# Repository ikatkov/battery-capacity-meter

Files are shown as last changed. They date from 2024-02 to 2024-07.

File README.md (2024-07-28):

# Assembly notes

Vref pin on Arduino Pro Mini breakout board is not on any pin, solder a wire to capacitor between 
pins 12 and 13. To the pin13 end.

Manufactured PCBs have a defect, bridge these tracks
see manufactured-pcb-defect.png

# 7 Segments text

Here is an example of which letters are possible

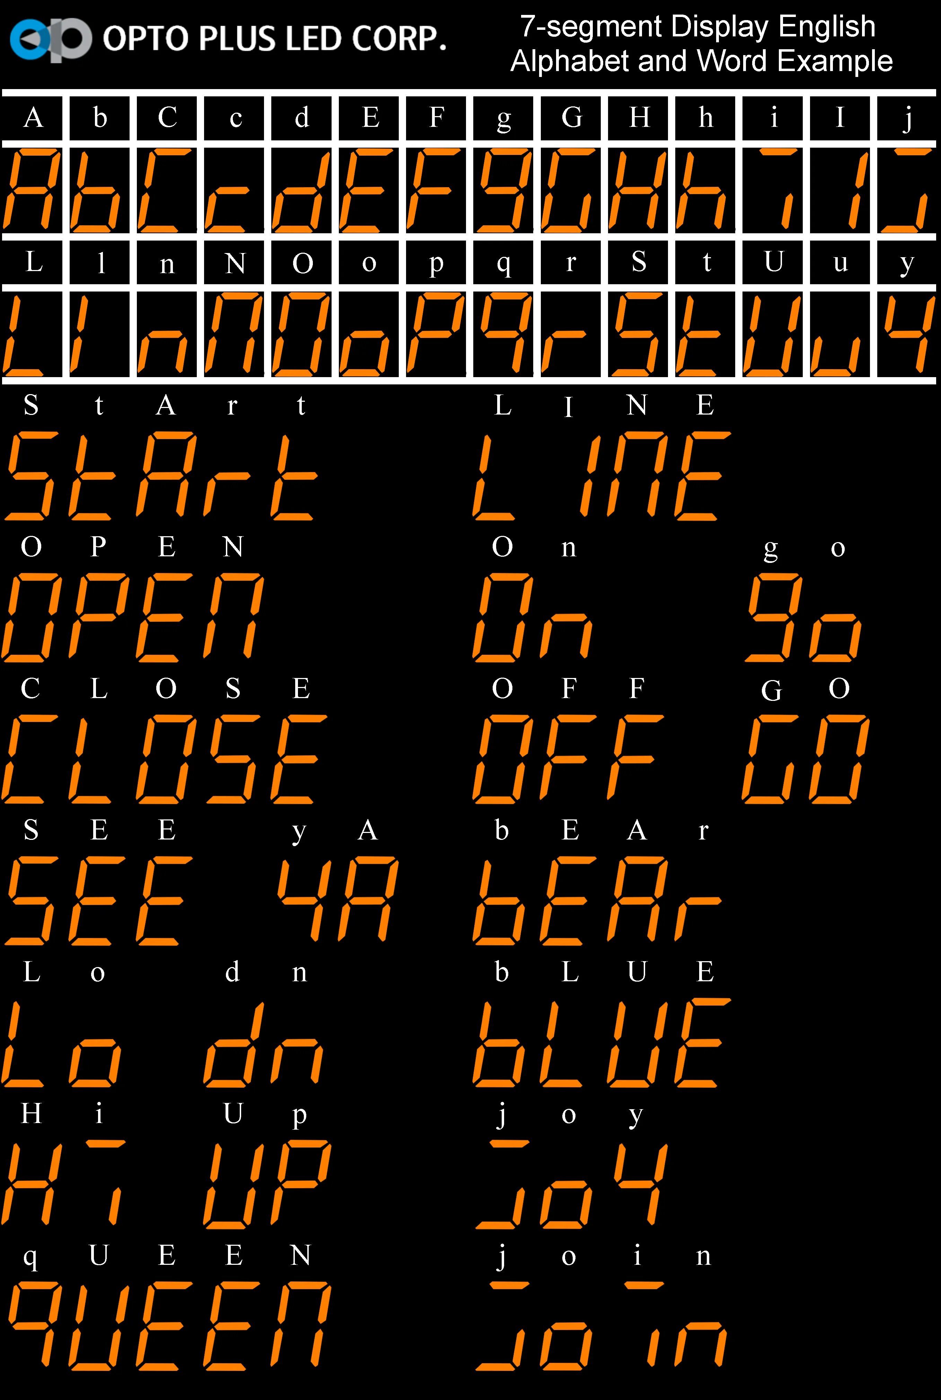
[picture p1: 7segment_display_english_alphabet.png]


A,b,C,c,d,E,F,g,G,H,h,i,I,j,L,l,n,N,O,o,P,q,r,S,t,U,u,y

# Notes

* The final PCB layout that I ordered from https://jlcpcb.com/ is not great. This is my almost first attempt to really use two sides with a lot of vias. Maybe next time use the lower side for horizontal signal traces and the top side for vertical? 

* Maybe replace 2.5V ref to MCU with feeding the whole MCU from 2.5V ref, it eliminates the extra wire.

* Next time make use wider ribbon cable - use more LEDs on the front panel to indicate the current mode and state

* Update the firmware to include trickle charge, it's especially noticeable when charging to the 3.8V for storage, once 
charging power is removed - voltage drops.

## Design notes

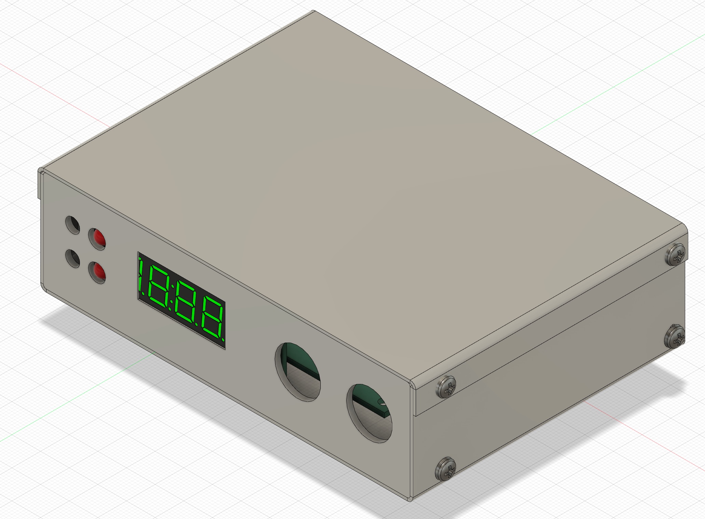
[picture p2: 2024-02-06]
box.jpg

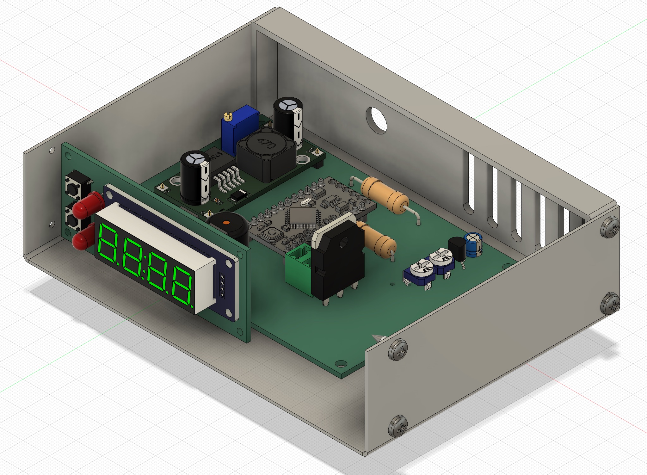
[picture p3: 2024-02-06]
box-inside.jpg

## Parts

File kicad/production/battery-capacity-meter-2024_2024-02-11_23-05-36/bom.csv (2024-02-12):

Designator | Footprint | Quantity | Value | LCSC Part #
AREF1 | SolderWire-0.5sqmm_1x01_D0.9mm_OD2.1mm | 1 | Pin20
BZ1 | Buzzer_12x9.5RM7.6 | 1 | Buzzer
Battery1 | JST_VH_B2P-VH-B_1x02_P3.96mm_Vertical | 1 | Charger
C1 | 1206 | 1 | 10n
C2 | 1206 | 1 | 100n
C4, C6 | 1206 | 2 | 10u
C5 | 1206 | 1 | 1u
C8 | 1206 | 1 | 100p
C9 | CP_Radial_D5.0mm_P2.50mm | 1 | 10u
D1 | D_DO-41_SOD81_P10.16mm_Horizontal | 1 | 1N4004
D2, D6 | D_MiniMELF | 2 | 1N4148
D3 | LED_D5.0mm | 1 | CHARGE
D4 | LED_D5.0mm | 1 | 1A
D5 | D_MiniMELF | 1 | 1N4732A 4.7V
D7, D9 | SOT-23 | 2 | BAT54S
H1, H2, H3, H4 | MountingHole_3.2mm_M3 | 4 | MountingHole
H5, H6, H7, H8 | MountingHole_2.2mm_M2 | 4 | MountingHole
J3 | IDC-Header_2x04_P2.54mm_Vertical | 1 | Conn_MainBoard
J4 | IDC-Header_2x04_P2.54mm_Vertical_SMD | 1 | Conn_DisplayBoard
J5 | JST_XH_B2B-XH-A_1x02_P2.50mm_Vertical | 1 | PWR
Q1 | SOT-23 | 1 | 2N3904
Q2 | SOT-23 | 1 | 2N3906
Q3 | TO-3P-3_Vertical | 1 | 2SD2390
Q6 | TO-220-3_Vertical | 1 | X0402MF
R1 | R_Axial_DIN0614_L14.3mm_D5.7mm_P15.24mm_Horizontal | 1 | 0.2-0.5R
R10, R11, R2, R20, R21, R22, R24, R25, R6, R7, R8 | 0805 | 11 | 10k
R12 | R_Axial_DIN0614_L14.3mm_D5.7mm_P25.40mm_Horizontal | 1 | 1R
R13, R16 | 0805 | 2 | 470
R14 | 0805 | 1 | 2k
R15, R18, R5, R9 | 0805 | 4 | 1k
R17 | 0805 | 1 | 680
R19 | 0805 | 1 | 3k
R23 | 2512 | 1 | R100
R26 | 0805 | 1 | 150R
R27 | 0805 | 1 | 1M
R3, R4 | 0805 | 2 | 2.2k
RV1, RV2 | Potentiometer_Runtron_RM-065_Vertical | 2 | 500
SW1 | SW_PUSH_6mm | 1 | CHARGE/DISCHARGE
SW2 | SW_PUSH_6mm | 1 | 1A MODE
TH1, TH2 | PTC_1A_radial | 2 | 1A
TP1 | SolderWire-0.5sqmm_1x01_D0.9mm_OD2.1mm | 1 | ISet
U1 | LM2596_StepDown_pot | 1 | LM2596_StepDown_Module
U10, U5, U9 | SOT-23 | 3 | AO3406
U2 | SO-8_3.9x4.9mm_P1.27mm | 1 | LM358
U3 | 7segments-medium | 1 | TM1637Display
U6 | TO-92_Wide | 1 | TL431LP
U7 | ARDUINO_PRO_MINI_NO_PRG_HEADER | 1 | Arduino_pro_mini
U8 | SO-8_3.9x4.9mm_P1.27mm | 1 | TP4056

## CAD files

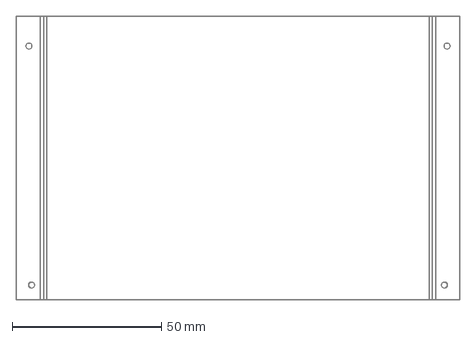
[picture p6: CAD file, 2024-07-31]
3d/top.dxf
148.5 x 95.0 mm

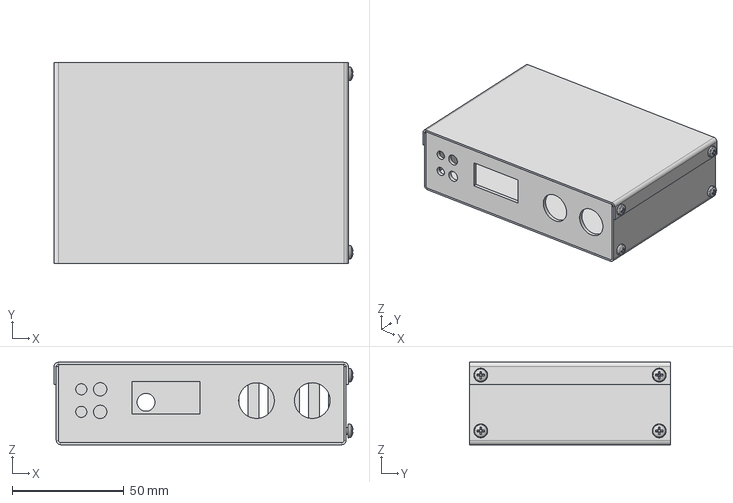
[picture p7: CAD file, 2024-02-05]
3d/enclosure.step
134.0 x 90.0 x 37.0 mm
Type II Cross Recessed Pan Head Tapping Screw ANSI B18.6.4 5-20 x 0.3 75 Type AB Steel Grade 2 Plain v1 x 4

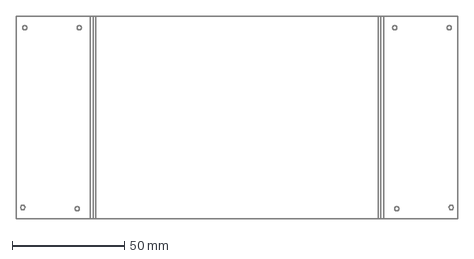
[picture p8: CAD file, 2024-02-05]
3d/bottom.dxf
196.5 x 90.0 mm

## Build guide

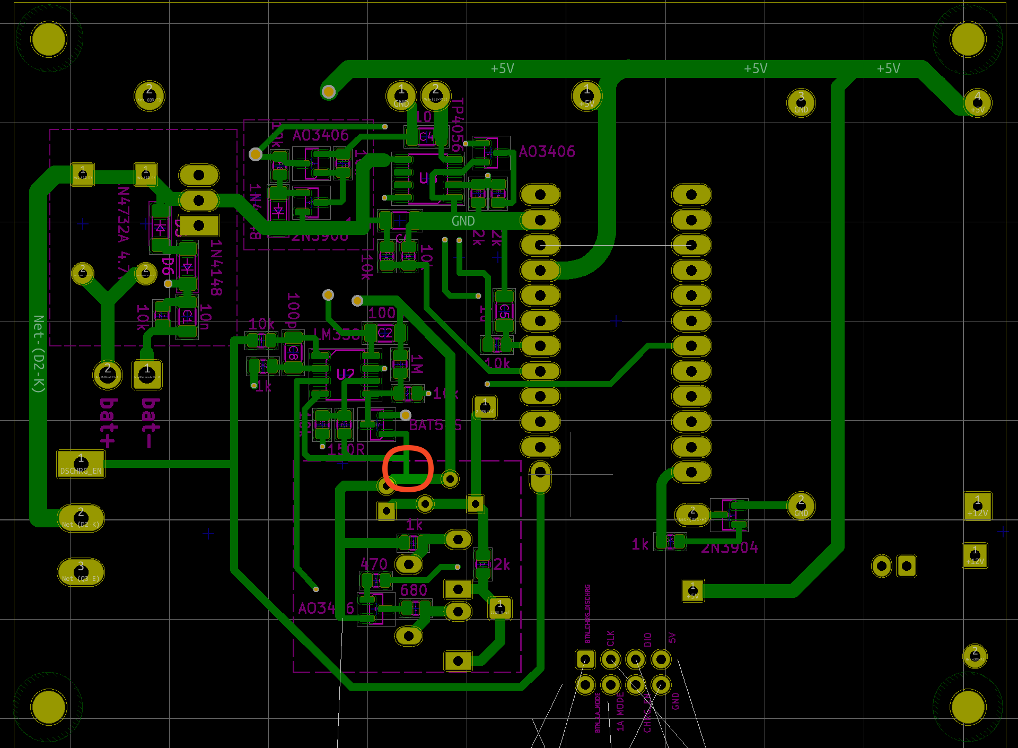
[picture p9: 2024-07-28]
manufactured-pcb-defect.png

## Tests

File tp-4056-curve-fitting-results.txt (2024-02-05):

0.5A 
=====
Fitted parameters for 4th-degree polynomial:  0.27035568*pow(voltage, 4) + -0.51039031*pow(voltage, 3) + 0.31013550*pow(voltage, 2) + 0.44244364*voltage + 0.00128515
Fitted parameters for 3rd-degree polynomial:  0.09325863*pow(voltage, 3) + -0.13783420*pow(voltage, 2) + 0.56727601*voltage + -0.00927211
Fitted parameters for 2nd-degree polynomial:  0.02794441*pow(voltage, 2) + 0.48445722*voltage + 0.00029737
Fitted parameters for linear function:  0.51579271*voltage + -0.00502295

1A 
=====
Fitted parameters for 4th-degree polynomial:  -0.50940504*pow(voltage, 4) + 1.11893064*pow(voltage, 3) + -0.80032945*pow(voltage, 2) + 1.19824953*voltage + -0.01151128
Fitted parameters for 3rd-degree polynomial:  0.02641582*pow(voltage, 3) + -0.03749443*pow(voltage, 2) + 1.00662362*voltage + 0.00093661
Fitted parameters for 2nd-degree polynomial:  0.00539237*pow(voltage, 2) + 0.98790520*voltage + 0.00265263
Fitted parameters for linear function:  0.99337865*voltage + 0.00176501

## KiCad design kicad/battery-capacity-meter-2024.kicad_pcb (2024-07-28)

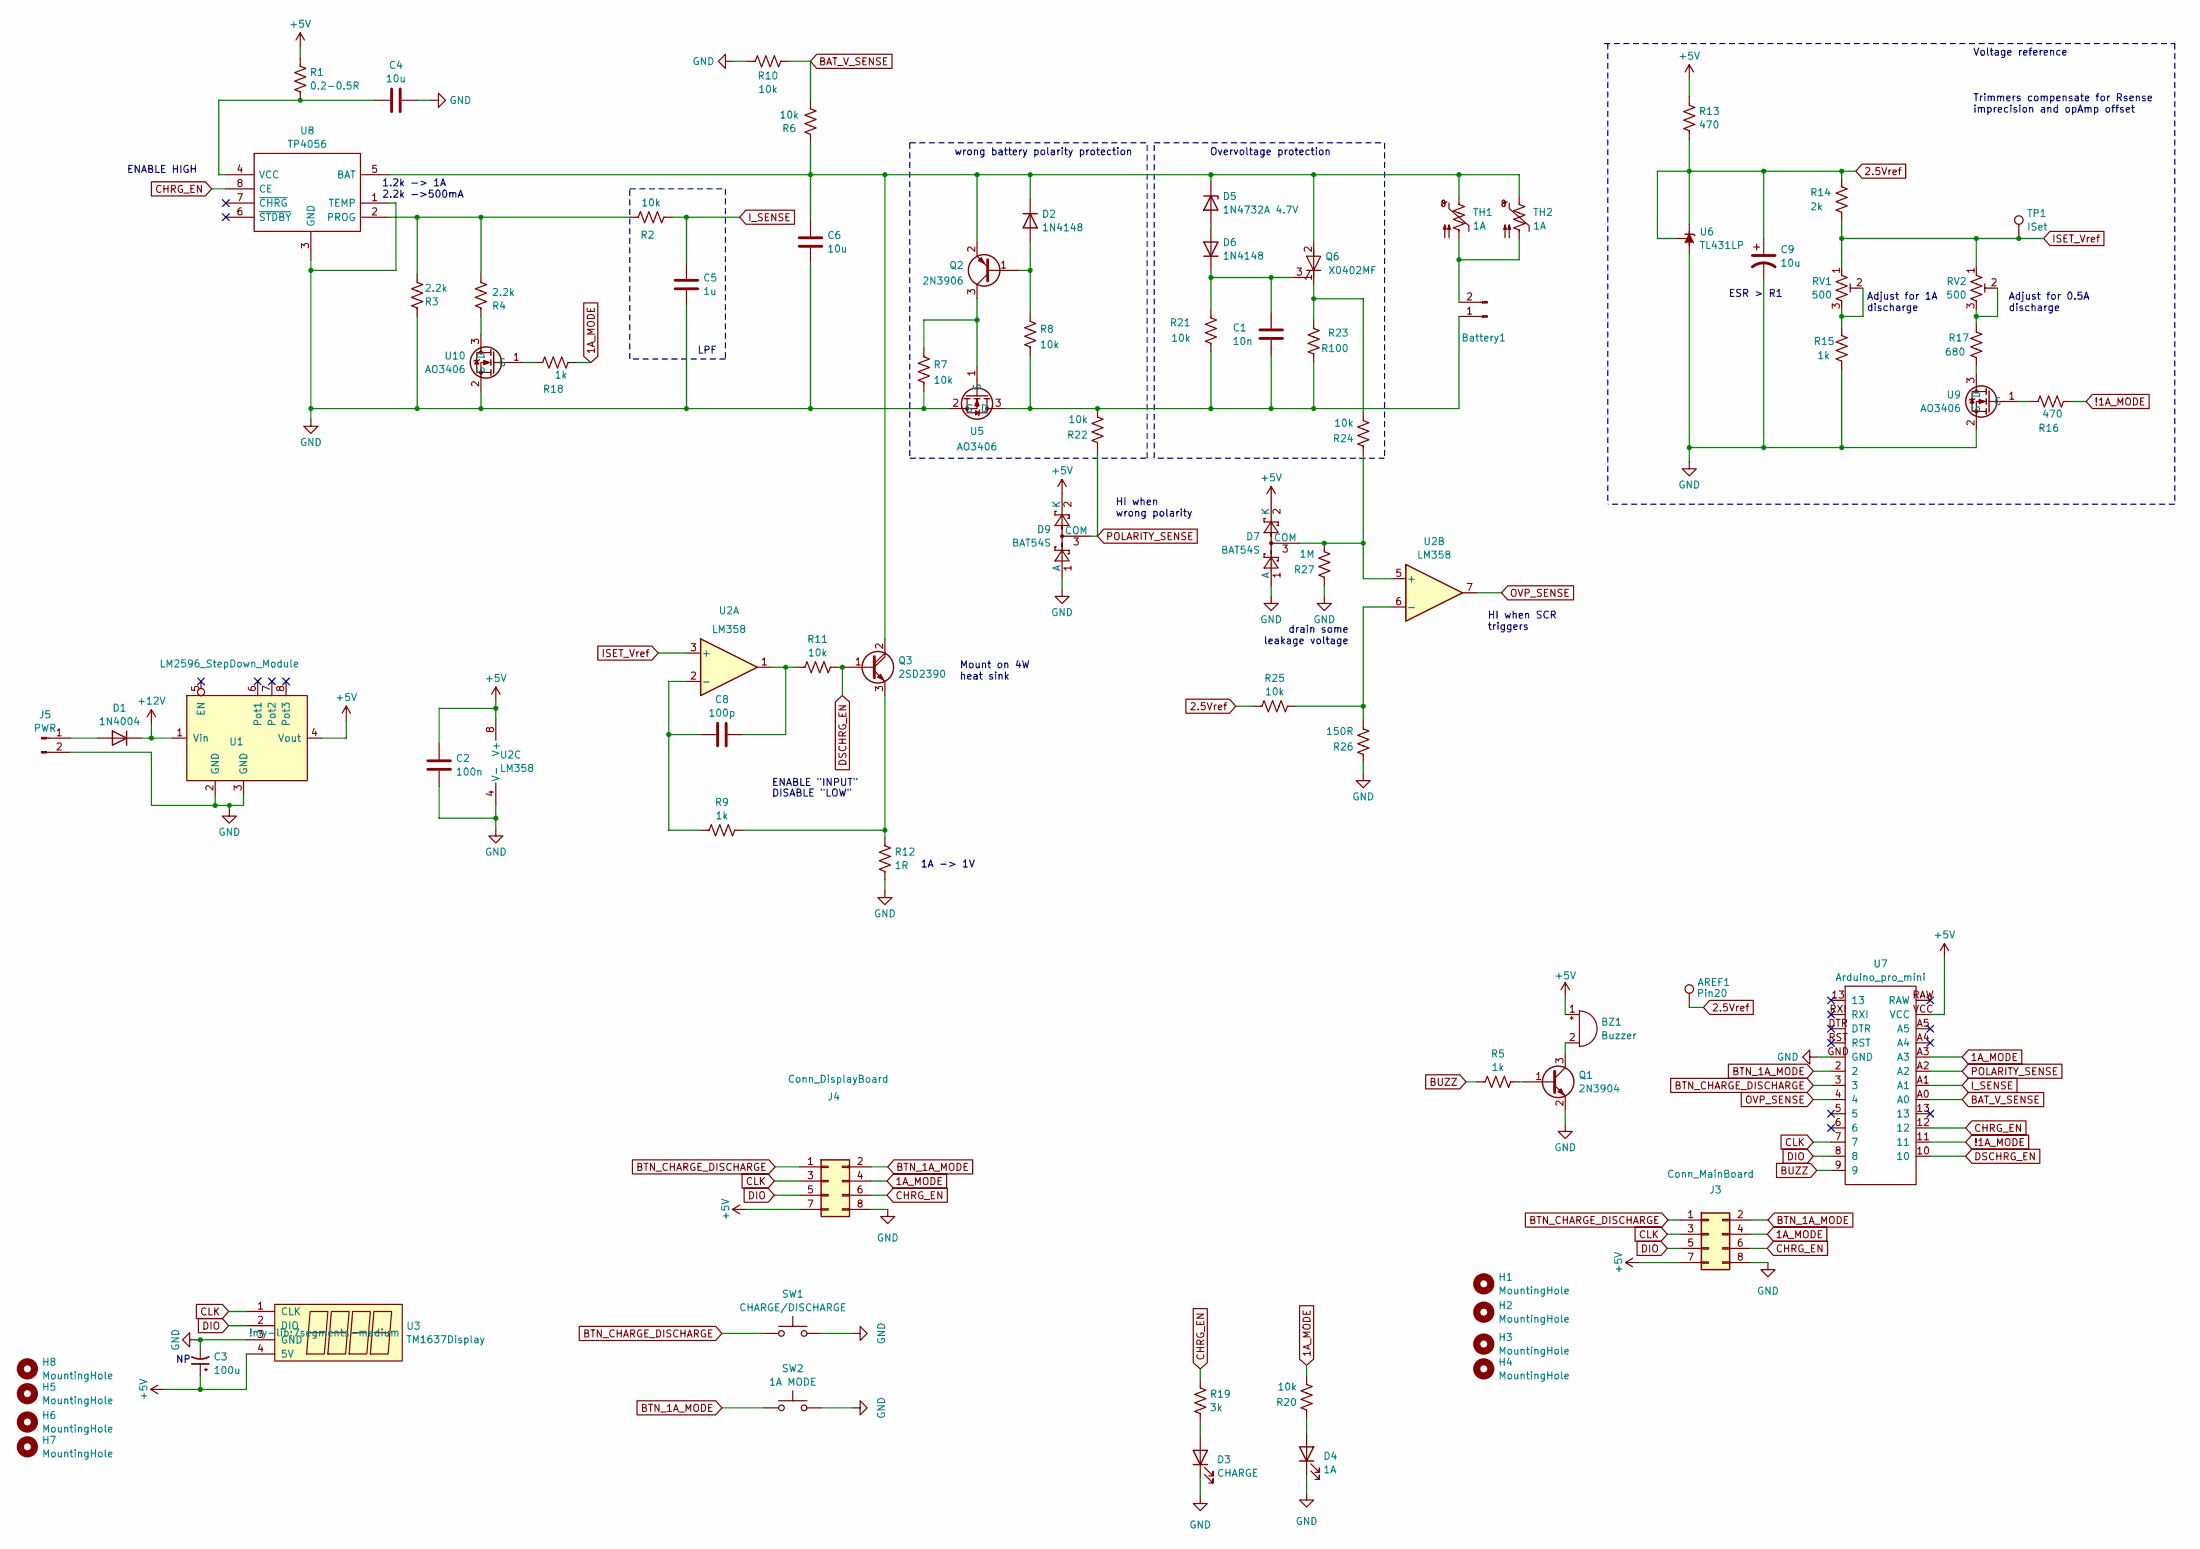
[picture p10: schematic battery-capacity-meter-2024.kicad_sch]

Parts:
AREF1: Pin20; SolderWire-0.5sqmm_1x01_D0.9mm_OD2.1mm
BZ1: Buzzer; Buzzer_12x9.5RM7.6
Battery1: Charger; JST_VH_B2P-VH-B_1x02_P3.96mm_Vertical
C1: 10n; C_1206_3216Metric
C2: 100n; C_1206_3216Metric
C3: 100u; CP_Radial_D8.0mm_P2.50mm
C4, C6: 10u; C_1206_3216Metric
C5: 1u; C_1206_3216Metric
C8: 100p; C_1206_3216Metric
C9: 10u; CP_Radial_D5.0mm_P2.50mm
D1: 1N4004; D_DO-41_SOD81_P10.16mm_Horizontal
D2, D6: 1N4148; D_MiniMELF
D3: CHARGE; LED_D5.0mm
D4: 1A; LED_D5.0mm
D5: 1N4732A 4.7V; D_MiniMELF
D7, D9: BAT54S; SOT-23
H1, H2, H3, H4: MountingHole; MountingHole_3.2mm_M3
H5, H6, H7, H8: MountingHole; MountingHole_2.2mm_M2
J3: Conn_MainBoard; IDC-Header_2x04_P2.54mm_Vertical
J4: Conn_DisplayBoard; IDC-Header_2x04_P2.54mm_Vertical_SMD
J5: PWR; JST_XH_B2B-XH-A_1x02_P2.50mm_Vertical
Q1: 2N3904; SOT-23
Q2: 2N3906; SOT-23
Q3: 2SD2390; TO-3P-3_Vertical
Q6: X0402MF; TO-220-3_Vertical
R1: 0.2-0.5R; R_Axial_DIN0614_L14.3mm_D5.7mm_P15.24mm_Horizontal
R2, R6, R7, R8, R10, R11, R20, R21, R22, R24, R25: 10k; R_0805_2012Metric
R3, R4: 2.2k; R_0805_2012Metric
R5, R9, R15, R18: 1k; R_0805_2012Metric
R12: 1R; R_Axial_DIN0614_L14.3mm_D5.7mm_P25.40mm_Horizontal
R13, R16: 470; R_0805_2012Metric
R14: 2k; R_0805_2012Metric
R17: 680; R_0805_2012Metric
R19: 3k; R_0805_2012Metric
R23: R100; R_2512_6332Metric
R26: 150R; R_0805_2012Metric
R27: 1M; R_0805_2012Metric
RV1, RV2: 500; Potentiometer_Runtron_RM-065_Vertical
SW1: CHARGE/DISCHARGE; SW_PUSH_6mm
SW2: 1A MODE; SW_PUSH_6mm
TH1, TH2: 1A; PTC_1A_radial
TP1: ISet; SolderWire-0.5sqmm_1x01_D0.9mm_OD2.1mm
U1: LM2596_StepDown_Module; LM2596_StepDown_pot
U2: LM358; SO-8_3.9x4.9mm_P1.27mm
U3: TM1637Display; 7segments-medium
U5, U9, U10: AO3406; SOT-23
U6: TL431LP; TO-92_Wide
U7: Arduino_pro_mini; ARDUINO_PRO_MINI_NO_PRG_HEADER
U8: TP4056; SO-8_3.9x4.9mm_P1.27mm; Manufacturer_Part_Number TP4056

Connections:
1A_MODE: J3.4, J4.4, R18.2, R20.1, U7.A3
2.5Vref: AREF1.1, C9.1, R13.2, R14.1, R25.1, U6.1 (REF), U6.3 (K)
!1A_MODE: R16.2, U7.11
+5V: BZ1.1 (-), C2.1, C3.1, D7.2 (K), D9.2 (K), J3.7, J4.7, R1.1, R13.1, U1.4 (Vout), U2.8 (V+), U3.4 (5V), U7.VCC
+12V: D1.1 (K), U1.1 (Vin)
BAT_V_SENSE: R6.2, R10.1, U7.A0
BTN_1A_MODE: J3.2, J4.2, SW2.1, U7.2
BTN_CHARGE_DISCHARGE: J3.1, J4.1, SW1.1, U7.3
BUZZ: R5.1, U7.9
CHRG_EN: J3.6, J4.6, R19.1, U7.12, U8.8 (CE)
CLK: J3.3, J4.3, U3.1 (CLK), U7.7
DIO: J3.5, J4.5, U3.2 (DIO), U7.8
DSCHRG_EN: Q3.1 (B), R11.2, U7.10
GND: C2.2, C3.2, C4.2, C5.2, C6.2, C9.2, D3.1 (K), D4.1 (K), D7.1 (A), D9.1 (A), J3.8, J4.8, J5.2, Q1.2 (E), R3.2, R7.1, R10.2, R12.1, R15.2, R26.2, R27.2, SW1.2, SW2.2, U1.2 (GND), U1.3 (GND), U2.4 (V-), U3.3 (GND), U5.2 (S), U6.2 (A), U7.GND, U8.1 (TEMP), U8.3 (GND), U9.2 (S), U10.2 (S)
ISET_Vref: R14.2, RV1.1, RV2.1, TP1.1, U2.3 (+)
I_SENSE: C5.1, R2.2, U7.A1
unnamed: BZ1.2 (+), Q1.3 (C)
unnamed: Battery1.1, C1.2, R8.1, R21.2, R22.1, R23.2, U5.3 (D)
unnamed: Battery1.2, TH1.2, TH2.2
unnamed: C8.2, R11.1, U2.1
unnamed: D1.2 (A), J5.1
unnamed: D2.2 (A), Q2.1 (B), R8.2
unnamed: C6.1, D2.1 (K), D5.1 (K), Q2.2 (E), Q3.2 (C), Q6.2 (A), Q6.4 (A), R6.1, TH1.1, TH2.1, U8.5 (BAT)
unnamed: D3.2 (A), R19.2
unnamed: D4.2 (A), R20.2
unnamed: D5.2 (A), D6.2 (A)
unnamed: C1.1, D6.1 (K), Q6.3 (G), R21.1
unnamed: D7.3 (COM), R24.2, R27.1, U2.5 (+)
unnamed: Q1.1 (B), R5.2
unnamed: Q2.3 (C), R7.2, U5.1 (G)
unnamed: Q3.3 (E), R9.2, R12.2
unnamed: Q6.1 (K), R23.1, R24.1
unnamed: R15.1, RV1.2, RV1.3
unnamed: R17.1, RV2.2, RV2.3
unnamed: C8.1, R9.1, U2.2 (-)
unnamed: R25.2, R26.1, U2.6 (-)
unnamed: R2.1, R3.1, R4.1, U8.2 (PROG)
unnamed: C4.1, R1.2, U8.4 (VCC)
unnamed: R17.2, U9.3 (D)
unnamed: R16.1, U9.1 (G)
unnamed: R4.2, U10.3 (D)
unnamed: R18.1, U10.1 (G)
OVP_SENSE: U2.7, U7.4
POLARITY_SENSE: D9.3 (COM), R22.2, U7.A2

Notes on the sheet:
ESR > R1
HI when SCR triggers
Voltage reference Trimmers compensate for Rsense imprecision and opAmp offset
HI when wrong polarity
Overvoltage protection
Adjust for 0.5A discharge
Mount on 4W heat sink
LPF
ENABLE "INPUT"
DISABLE "LOW"
Adjust for 1A discharge
ENABLE HIGH
drain some leakage voltage
1A -> 1V
1.2k -> 1A 2.2k ->500mA
wrong battery polarity protection

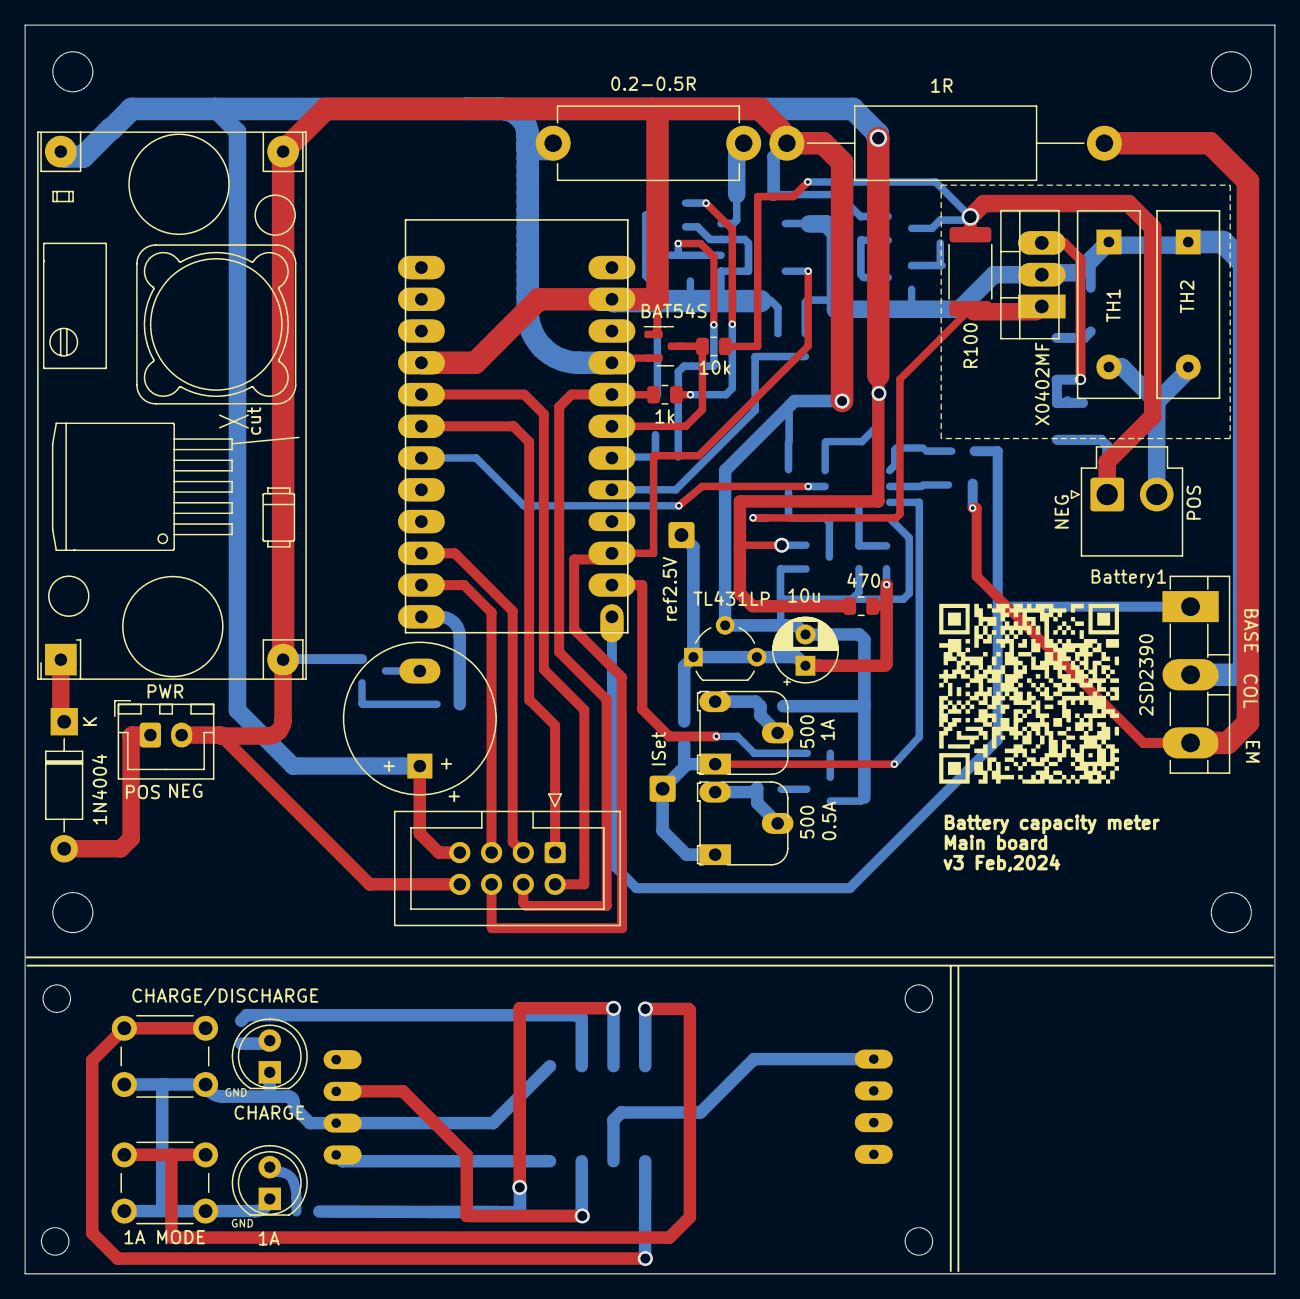
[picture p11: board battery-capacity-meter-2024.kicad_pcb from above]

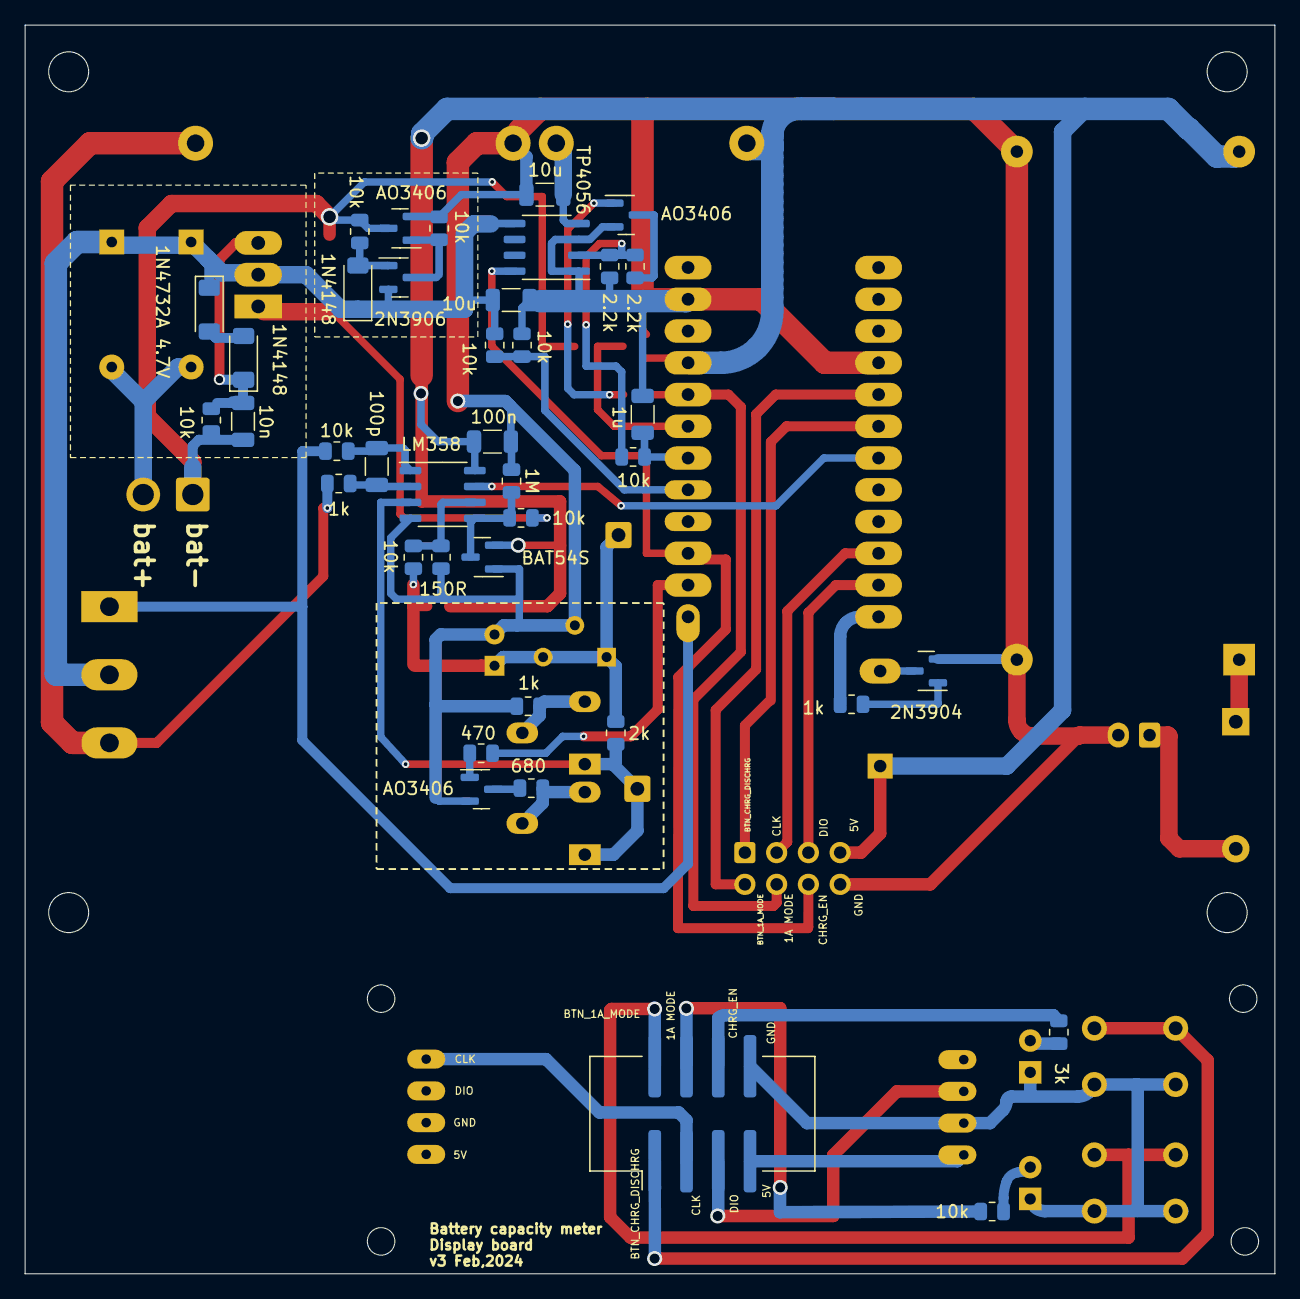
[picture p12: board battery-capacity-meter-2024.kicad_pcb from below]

Board: 2 copper layers, 100.0 x 99.9 mm, 76 parts (39 on the bottom side), 44 nets.

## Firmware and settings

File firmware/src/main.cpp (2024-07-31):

#include <Arduino.h>
#include <OneButton.h>
#include <TM1637Display.h>
#include <movingAvg.h>
#include <CustomSegments.h>

#define BATTERY_VOLTAGE_PIN A0
#define CHARGE_I_SENSE_PIN A1
#define BATTERY_POLARITY_SENSE_PIN A2
#define OVERVOLTAGE_SENSE_PIN 4

#define ONE_A_MODE_PIN A3
#define CHARGE_EN_PIN 12
#define NOT_ONE_A_MODE_PIN 11
#define DISCHARGE_EN_PIN 10
#define BUZZER_PIN 9

// display
#define DIO_PIN 8
#define CLK_PIN 7

#define CHARGE_DISCHARGE_BUTTON_PIN 3
#define ONE_AMP_BUTTON_PIN 2

OneButton chargeDischargeButton = OneButton(CHARGE_DISCHARGE_BUTTON_PIN, true, true);
OneButton oneAmpButton = OneButton(ONE_AMP_BUTTON_PIN, true, true);
TM1637Display display(CLK_PIN, DIO_PIN);

#define BAT_LOW_VOLTAGE_CUT_OFF 3000
#define BAT_HIGH_VOLTAGE_CUT_OFF 4150
#define BAT_HIGH_VOLTAGE_STORAGE_CUT_OFF 3800

enum CYCLE_MODE
{
    CHARGE_ONLY,
    CHANGE_DISCHARGE,
    CHANGE_DISCHARGE_STORAGE,
    STORAGE_ONLY,
    DISCHARGE_ONLY,
};

enum STATE
{
    IDLE,
    CHARGING,
    SECOND_CHARGING,
    DISCHARGING,
    DONE,
    ERROR,
};

STATE state = IDLE;
CYCLE_MODE cycleMode = CHANGE_DISCHARGE_STORAGE;
bool oneAmpState = false; // false = 0.5A, true = 1A

movingAvg chargeCurrent(12);  // use 12 data points for the moving average, every 5sec it's 60sec averaging
movingAvg batteryVoltage(12); // use 12 data points for the moving average, every 5sec it's 60sec averaging when charging, 12sec when discharging

int batteryPercentage = 0;
int batteryCapacitymAh = 0;

unsigned long lastTimeChargeCurrentRead = millis();
unsigned long lastTimeBatteryVoltageRead = millis();
unsigned long lastTimeMessageDisplayed = millis();
unsigned long lastTimeBatteryPolarityRead = millis();
unsigned long dischargeIntervalStartedMs = 0;
bool messageToggle = false;
byte messageToggleTristate = 0;

void readBatteryVoltage(int delayMs = 0);

void setCycleMode(CYCLE_MODE cycleModeValue)
{
    cycleMode = cycleModeValue;
    if (cycleMode == CHARGE_ONLY)
    {
        display.setSegments(TEXT_CHRG);
        delay(500);
        display.setSegments(TEXT_ONLY);
        delay(500);
    }
    else if (cycleMode == CHANGE_DISCHARGE)
    {
        display.setSegments(TEXT_CHRG);
        delay(500);
        display.setSegments(TEXT_TEST);
        delay(500);
    }
    else if (cycleMode == CHANGE_DISCHARGE_STORAGE)
    {
        display.setSegments(TEXT_CHRG);
        delay(500);
        display.setSegments(TEXT_TEST);
        delay(500);
        display.setSegments(TEXT_STOR);
        delay(500);
    }
    else if (cycleMode == STORAGE_ONLY)
    {
        display.setSegments(TEXT_STOR);
        delay(500);
        display.setSegments(TEXT_ONLY);
        delay(500);
    }
    else if (cycleMode == DISCHARGE_ONLY)
    {
        display.setSegments(TEXT_TEST);
        delay(500);
        display.setSegments(TEXT_ONLY);
        delay(500);
    }
}

void beep(int duratuionMs = 100)
{
    digitalWrite(BUZZER_PIN, HIGH);
    delay(100);
    digitalWrite(BUZZER_PIN, LOW);
}

void longBeep()
{
    beep(300);
}

void trippleBeep()
{
    beep();
    delay(200);
    beep();
    delay(200);
    beep();
    delay(200);
}

void setState(STATE stateValue)
{
    state = stateValue;
    if (state == CHARGING || state == SECOND_CHARGING)
    {
        display.setSegments(TEXT_CHRG);
        // charge
        digitalWrite(CHARGE_EN_PIN, HIGH);
        pinMode(DISCHARGE_EN_PIN, OUTPUT);
        digitalWrite(DISCHARGE_EN_PIN, LOW);
    }
    else if (state == DISCHARGING)
    {
        batteryCapacitymAh = 0;
        batteryVoltage.reset();
        display.setSegments(TEXT_TEST);
        // discharge
        digitalWrite(CHARGE_EN_PIN, LOW);
        pinMode(DISCHARGE_EN_PIN, INPUT);
    }
    else
    {
        digitalWrite(CHARGE_EN_PIN, LOW);
        pinMode(DISCHARGE_EN_PIN, OUTPUT);
        digitalWrite(DISCHARGE_EN_PIN, LOW);
    }
    if (state == DONE)
    {
        batteryVoltage.reset();
        display.setSegments(TEXT_DONE);
        lastTimeMessageDisplayed = millis();
        longBeep();
        longBeep();
        delay(500);
        longBeep();
        longBeep();
        delay(500);
        longBeep();
        longBeep();
    }
    if (state == ERROR)
    {
        batteryVoltage.reset();
    }
}

void onChargeDischargeButtonLngPressStart()
{
    Serial.println(F("onChargeDischargeButtonLngPressStart"));
    longBeep();
    if (state == IDLE)
    {
        setCycleMode(CYCLE_MODE((cycleMode + 1) % 5));
    }
}

void onChargeDischargeButtonClick()
{
    Serial.println(F("onChargeDischargeButtonClick"));
    beep();
    if (state == IDLE)
    {
        // check if battery connected
        readBatteryVoltage();
        if (batteryVoltage.getAvg() < 1000)
        {
            Serial.println(F("Battery disconnected"));
            display.setSegments(TEXT_BATT);
            longBeep();
            longBeep();
            longBeep();
            setState(IDLE);
        }
        else if (cycleMode == DISCHARGE_ONLY)
        {
            Serial.println(F("Start discharging..."));
            setState(DISCHARGING);
            display.setSegments(TEXT_TEST);
            delay(1000);
        }
        else
        {
            Serial.println(F("Start charging..."));
            setState(CHARGING);
            display.setSegments(TEXT_CHRG);
            delay(1000);
        }
    }
    else if (state == CHARGING)
    {
        // before starting the discharge, check if battery voltage is too low
        readBatteryVoltage();
        if (batteryVoltage.getAvg() <= BAT_LOW_VOLTAGE_CUT_OFF)
        {
            Serial.println(F("Battery voltage too low"));
            display.setSegments(TEXT_BATT);
            longBeep();
            delay(1000);
            display.setSegments(TEXT_LO);
            longBeep();
            delay(1000);
            display.setSegments(TEXT_CHRG);
            return;
        }
        else
        {
            Serial.println(F("Starting discharge"));
            display.setSegments(TEXT_TEST);
            trippleBeep();

            setState(DISCHARGING);
            dischargeIntervalStartedMs = millis();
            Serial.print(F("Discharge interval started:\t"));
            Serial.println(dischargeIntervalStartedMs);
        }
    }
    else if (state == DISCHARGING)
    {
        Serial.println(F("Stop discharge"));
        setState(DONE);
    }
    else if (state == DONE || state == ERROR)
    {
        Serial.println(F("Go to idle"));
        setState(IDLE);
    }
}

void onOneAmpButtonClick()
{
    Serial.println(F("onOneAmpButtonClick"));
    oneAmpState = !oneAmpState;
    Serial.println(oneAmpState ? F(" 1A") : F(" 0.5A"));
    if (oneAmpState)
    {
        // 1A
        digitalWrite(ONE_A_MODE_PIN, HIGH);
        digitalWrite(NOT_ONE_A_MODE_PIN, LOW);
    }
    else
    {
        // 0.5A
        digitalWrite(ONE_A_MODE_PIN, LOW);
        digitalWrite(NOT_ONE_A_MODE_PIN, HIGH);
    }
    if (state == DISCHARGING)
    {
        display.setSegments(TEXT_TEST);
        trippleBeep();
        // reset battery capacity
        batteryCapacitymAh = 0;
        dischargeIntervalStartedMs = millis();
        Serial.print(F("Discharge interval started:\t"));
        Serial.println(dischargeIntervalStartedMs);
    }
}

void setOneAmpMode(bool state)
{
    oneAmpState = state;
    if (oneAmpState)
    {
        // 1A
        digitalWrite(ONE_A_MODE_PIN, HIGH);
        digitalWrite(NOT_ONE_A_MODE_PIN, LOW);
    }
    else
    {
        // 0.5A
        digitalWrite(ONE_A_MODE_PIN, LOW);
        digitalWrite(NOT_ONE_A_MODE_PIN, HIGH);
    }
}

float computeChargeCurrent(float voltage)
{
    if (oneAmpState)
    {
        return -0.50940504 * pow(voltage, 4) + 1.11893064 * pow(voltage, 3) + -0.80032945 * pow(voltage, 2) + 1.19824953 * voltage + -0.01151128;
    }
    else
    {
        return 0.27035568 * pow(voltage, 4) + -0.51039031 * pow(voltage, 3) + 0.31013550 * pow(voltage, 2) + 0.44244364 * voltage + 0.00128515;
    }
}

void readBatteryVoltage(int delayMs)
{
    if (state == CHARGING)
    {
        // stop charging to read battery voltage
        digitalWrite(CHARGE_EN_PIN, LOW);
        delay(delayMs);
    }

    // read battery voltage
    int sensorValue = analogRead(BATTERY_VOLTAGE_PIN);
    // voltage higher than some floating voltage
    if (sensorValue > 150)
    {
        // V = (sensorValue + 0.5) * V_REF / 1024.0
        int batteryVoltageValue = round(1000 * 2 * ((sensorValue + 0.5) * 2.5 / 1024.0));
        batteryVoltage.reading(batteryVoltageValue);
        batteryPercentage = map(batteryVoltage.getAvg(), BAT_LOW_VOLTAGE_CUT_OFF, BAT_HIGH_VOLTAGE_CUT_OFF, 0, 100);

        Serial.print("Voltage =\t");
        Serial.print(sensorValue);
        Serial.print("\t");
        Serial.print(batteryVoltageValue);
        Serial.print("\t");
        Serial.print(batteryVoltage.getAvg());
        Serial.print("\t");
        Serial.print(batteryPercentage);
        Serial.println("%");
    }
    else
    {
        batteryVoltage.reset();
    }

    if (state == CHARGING)
    {
        // restore charge state
        digitalWrite(CHARGE_EN_PIN, HIGH);
    }
}

void readChargeCurrent()
{
    int sensorValue = analogRead(CHARGE_I_SENSE_PIN);
    // V = (sensorValue + 0.5) * V_REF / 1024.0
    float voltage = (sensorValue + 0.5) * 2.5 / 1024.0;
    int chargeCurrentValue = round(1000 * max(0, computeChargeCurrent(voltage))); // charging current in mA
    chargeCurrent.reading(chargeCurrentValue);
    Serial.print("Charge Current =\t");
    Serial.print(sensorValue);
    Serial.print("\t");
    Serial.print(voltage);
    Serial.print("\t");
    Serial.print(chargeCurrentValue);
    Serial.print("\t");
    Serial.println(chargeCurrent.getAvg());
}

void setup()
{
    pinMode(BATTERY_VOLTAGE_PIN, INPUT);
    pinMode(CHARGE_I_SENSE_PIN, INPUT);
    pinMode(BATTERY_POLARITY_SENSE_PIN, INPUT);
    pinMode(OVERVOLTAGE_SENSE_PIN, INPUT);

    pinMode(CHARGE_EN_PIN, OUTPUT);
    pinMode(ONE_A_MODE_PIN, OUTPUT);
    pinMode(NOT_ONE_A_MODE_PIN, OUTPUT);
    pinMode(BUZZER_PIN, OUTPUT);
    analogReference(EXTERNAL);

    pinMode(DIO_PIN, OUTPUT);
    pinMode(CLK_PIN, OUTPUT);

    pinMode(DISCHARGE_EN_PIN, INPUT);

    setOneAmpMode(false);
    setState(IDLE);
    setCycleMode(CHANGE_DISCHARGE);

    Serial.begin(38400);
    Serial.println(F("booting up"));

    digitalWrite(BUZZER_PIN, HIGH);
    delay(100);

    display.setBrightness(255, true);
    display.clear();

    digitalWrite(BUZZER_PIN, LOW);

    chargeDischargeButton.attachClick(onChargeDischargeButtonClick);
    chargeDischargeButton.attachLongPressStart(onChargeDischargeButtonLngPressStart);
    oneAmpButton.attachClick(onOneAmpButtonClick);

    chargeCurrent.begin();
    batteryVoltage.begin();
}

void loop()
{
    chargeDischargeButton.tick();
    oneAmpButton.tick();

    if (lastTimeBatteryPolarityRead + 500 < millis())
    {
        bool correctBatteryPolarity = !digitalRead(BATTERY_POLARITY_SENSE_PIN);
        if (!correctBatteryPolarity)
        {
            Serial.println(F("Wrong battery polarity"));
            display.setSegments(TEXT_BATT);
            longBeep();
            longBeep();
            longBeep();
        }

        bool overVoltage = digitalRead(OVERVOLTAGE_SENSE_PIN);
        if (overVoltage)
        {
            // when battery is not connected - this is HIGH,
            // because SCR triggers, check battery voltage to see if any battery connected
            readBatteryVoltage(10);
            if (batteryVoltage.getAvg() > 1000)
            {
                Serial.println(F("Overvoltage"));
                display.setSegments(TEXT_ERR_1_OVERVOLTAGE);
                longBeep();
                longBeep();
                longBeep();
            }
        }
        lastTimeBatteryPolarityRead = millis();
    }

    // ============ Charge =================
    if (state == CHARGING || state == SECOND_CHARGING)
    {
        // read battery voltage every 5 seconds when charging
        if (lastTimeBatteryVoltageRead + 5000 < millis())
        {
            readBatteryVoltage(10);
            lastTimeBatteryVoltageRead = millis();
            if (batteryVoltage.getAvg() < 1000)
            {
                Serial.println(F("Battery disconnected"));
                display.setSegments(TEXT_ERR_2_BATT_DISCONNECTD_MID_CHARGE);
                longBeep();
                longBeep();
                longBeep();
                setState(ERROR);
                return;
            }
        }

        // display battery voltage and percentage every 1 seconds
        if (millis() - lastTimeMessageDisplayed > 1000)
        {
            lastTimeMessageDisplayed = millis();
            messageToggle = !messageToggle;
            if (messageToggle)
            {
                display.showNumberDecEx(batteryVoltage.getAvg(), 0b10000000, false);
            }
            else
            {
                display.setSegments(TEXT_PERCENT);
                display.showNumberDec(batteryPercentage, false, 2, 0);
            }
        }

        // are we done charging for storage?
        if (batteryVoltage.getAvg() > BAT_HIGH_VOLTAGE_STORAGE_CUT_OFF &&
            (cycleMode == STORAGE_ONLY || (cycleMode == CHANGE_DISCHARGE_STORAGE && state == SECOND_CHARGING)))
        {
            Serial.println(F("Done charging for storage"));
            setState(DONE);
        }
        // read charge current every 1 seconds when charging
        if (lastTimeChargeCurrentRead + 1000 < millis())
        {
            readChargeCurrent();
            lastTimeChargeCurrentRead = millis();
        }

        if (chargeCurrent.getAvg() < 50 || batteryVoltage.getAvg() > BAT_HIGH_VOLTAGE_CUT_OFF)
        {
            // check if battery connected
            readBatteryVoltage(1000);
            if (batteryVoltage.getAvg() < 1000)
            {
                Serial.println(F("Battery disconnected mid charge"));
                display.setSegments(TEXT_ERR_2_BATT_DISCONNECTD_MID_CHARGE);
                longBeep();
                longBeep();
                longBeep();
                setState(ERROR);
                return;
            }
            // charging is done
            if (cycleMode == CHARGE_ONLY)
            {
                Serial.println(F("Done charging only"));
                setState(DONE);
            }
            else if (cycleMode == CHANGE_DISCHARGE || (cycleMode == CHANGE_DISCHARGE_STORAGE && state == CHARGING))
            {
                Serial.println(F("Starting discharge, after full charge"));
                display.setSegments(TEXT_TEST);
                trippleBeep();

                dischargeIntervalStartedMs = millis();
                setState(DISCHARGING);
            }
        }
    }
    else if (state == DISCHARGING)
    {
        // ============ Discharge ============
        // read battery voltage every 1 seconds when discharging
        if (lastTimeBatteryVoltageRead + 1000 < millis())
        {
            readBatteryVoltage();
            lastTimeBatteryVoltageRead = millis();

            // 500mA*h discharge in mA*second is 500/3600 = 0.13888888888mAh per millisecond
            unsigned long elapsedTimeMs = millis() - dischargeIntervalStartedMs;
            Serial.print(F("elapsedTimeMs=\t"));
            Serial.println(elapsedTimeMs);
            double batteryCapacity = (double)elapsedTimeMs / 3600 / 1000 * (oneAmpState ? 1000 : 500);
            batteryCapacitymAh = round(batteryCapacity);

            Serial.print(F("Discharge battery capacity (mA*h)=\t"));
            Serial.println(batteryCapacitymAh);
            display.showNumberDec(batteryCapacitymAh);

            messageToggleTristate = (messageToggleTristate + 1) % 3;
            if (messageToggleTristate == 0)
            {
                display.showNumberDec(batteryCapacitymAh);
            }
            else if (messageToggleTristate == 1)
            {
                display.setSegments(TEXT_PERCENT);
                display.showNumberDec(batteryPercentage, false, 2, 0);
            }
            else
            {
                display.showNumberDecEx(batteryVoltage.getAvg(), 0b10000000, false);
            }
        }

        if (batteryVoltage.getAvg() < 1000)
        {
            Serial.println(F("Battery disconnected mid discharge"));
            display.setSegments(TEXT_ERR_3_BATT_DISCONNECTD_MID_DISCHARGE);
            longBeep();
            longBeep();
            longBeep();
            setState(ERROR);
            return;
        }
        else if (batteryVoltage.getAvg() < BAT_LOW_VOLTAGE_CUT_OFF)
        {
            Serial.println(F("Done discharge, battery voltage too low"));
            if (cycleMode == CHANGE_DISCHARGE)
            {
                setState(DONE);
            }
            else if (cycleMode == CHANGE_DISCHARGE_STORAGE)
            {
                Serial.println(F("Done discharge, battery voltage too low. Starting charge to storage voltage..."));
                setState(SECOND_CHARGING);
            }
        }
    }
    else if (state == DONE)
    {
        if (millis() - lastTimeMessageDisplayed > 1000)
        {
            lastTimeMessageDisplayed = millis();
            messageToggle = !messageToggle;
            if (messageToggle)
            {
                display.setSegments(TEXT_DONE);
            }
            else if (cycleMode != CHARGE_ONLY && cycleMode != STORAGE_ONLY)
            {
                Serial.println(batteryCapacitymAh);
                display.showNumberDec(batteryCapacitymAh);
            }
        }
    }
    else if (state == IDLE)
    {
        if (millis() - lastTimeMessageDisplayed > 500)
        {
            lastTimeMessageDisplayed = millis();
            messageToggle = !messageToggle;
            if (messageToggle)
            {
                if (cycleMode == CHARGE_ONLY)
                    display.setSegments(TEXT_ON1);
                else if (cycleMode == CHANGE_DISCHARGE)
                    display.setSegments(TEXT_ON2);
                else if (cycleMode == CHANGE_DISCHARGE_STORAGE)
                    display.setSegments(TEXT_ON3);
                else if (cycleMode == STORAGE_ONLY)
                    display.setSegments(TEXT_ON4);
                else if (cycleMode == DISCHARGE_ONLY)
                    display.setSegments(TEXT_ON5);
            }
            else
            {
                readBatteryVoltage();
                // if voltage is too low, there is no battery connected
                if (batteryVoltage.getAvg() > 1000)
                    display.showNumberDecEx(batteryVoltage.getAvg(), 0b10000000, false);
            }
        }
    }

    delay(10);
}

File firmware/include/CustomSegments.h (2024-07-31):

// All segments
//  SEG_A | SEG_B | SEG_C | SEG_D | SEG_E | SEG_F | SEG_G
const uint8_t TEXT_ON1[] = {
    SEG_A | SEG_B | SEG_C | SEG_D | SEG_E | SEG_F, // O
    SEG_C | SEG_E | SEG_G,                         // n
    0,                                             // space
    SEG_B | SEG_C                                  // 1
};

const uint8_t TEXT_ON2[] = {
    SEG_A | SEG_B | SEG_C | SEG_D | SEG_E | SEG_F, // O
    SEG_C | SEG_E | SEG_G,                         // n
    0,                                             // space
    SEG_A | SEG_B | SEG_D | SEG_E | SEG_G          // 2
};

const uint8_t TEXT_ON3[] = {
    SEG_A | SEG_B | SEG_C | SEG_D | SEG_E | SEG_F, // O
    SEG_C | SEG_E | SEG_G,                         // n
    0,                                             // space
    SEG_A | SEG_B | SEG_C | SEG_D | SEG_G          // 3
};

const uint8_t TEXT_ON4[] = {
    SEG_A | SEG_B | SEG_C | SEG_D | SEG_E | SEG_F, // O
    SEG_C | SEG_E | SEG_G,                         // n
    0,                                             // space
    SEG_B | SEG_C | SEG_F | SEG_G                  // 4
};

const uint8_t TEXT_ON5[] = {
    SEG_A | SEG_B | SEG_C | SEG_D | SEG_E | SEG_F, // O
    SEG_C | SEG_E | SEG_G,                         // n
    0,                                             // space
    SEG_A | SEG_C | SEG_D | SEG_F | SEG_G                  // 5
};

const uint8_t TEXT_CHRG[] = {
    SEG_A | SEG_D | SEG_E | SEG_F,         // C
    SEG_B | SEG_C | SEG_E | SEG_F | SEG_G, // H
    SEG_E | SEG_G,                         // r
    SEG_A | SEG_C | SEG_D | SEG_E | SEG_F  // G
};

const uint8_t TEXT_ONLY[] = {
    SEG_C | SEG_D | SEG_E | SEG_G, // o
    SEG_C | SEG_E | SEG_G,         // n
    SEG_B | SEG_C,                 // l
    0                              // space
};

const uint8_t TEXT_TEST[] = {
    SEG_D | SEG_E | SEG_F | SEG_G,         // t
    SEG_A | SEG_D | SEG_E | SEG_F | SEG_G, // E
    SEG_A | SEG_C | SEG_D | SEG_F | SEG_G, // S
    SEG_D | SEG_E | SEG_F | SEG_G          // t
};

const uint8_t TEXT_DONE[] = {
    SEG_B | SEG_C | SEG_D | SEG_E | SEG_G, // d
    SEG_C | SEG_D | SEG_E | SEG_G,         // o
    SEG_C | SEG_E | SEG_G,                 // n
    SEG_A | SEG_D | SEG_E | SEG_F | SEG_G  // E
};

const uint8_t TEXT_BATT[] = {
    SEG_C | SEG_D | SEG_E | SEG_F | SEG_G,         // B
    SEG_A | SEG_B | SEG_C | SEG_E | SEG_F | SEG_G, // A
    SEG_D | SEG_E | SEG_F | SEG_G,                 // t
    SEG_D | SEG_E | SEG_F | SEG_G                  // t
};

// Overvoltage, either from the charger or the battery
const uint8_t TEXT_ERR_1_OVERVOLTAGE[] = {
    SEG_A | SEG_D | SEG_E | SEG_F | SEG_G, // E
    SEG_E | SEG_G,                         // r
    SEG_E | SEG_G,                         // r
    SEG_B | SEG_C                          // 1
};

// Battery disconnected mid charge process
const uint8_t TEXT_ERR_2_BATT_DISCONNECTD_MID_CHARGE[] = {
    SEG_A | SEG_D | SEG_E | SEG_F | SEG_G, // E
    SEG_E | SEG_G,                         // r
    SEG_E | SEG_G,                         // r
    SEG_A | SEG_B | SEG_D | SEG_E | SEG_G  // 2
};

// Battery disconnected mid discharge process
const uint8_t TEXT_ERR_3_BATT_DISCONNECTD_MID_DISCHARGE[] = {
    SEG_A | SEG_D | SEG_E | SEG_F | SEG_G, // E
    SEG_E | SEG_G,                         // r
    SEG_E | SEG_G,                         // r
    SEG_A | SEG_B | SEG_C | SEG_D | SEG_G  // 3
};

const uint8_t TEXT_LO[] = {
    SEG_B | SEG_C | SEG_D | SEG_E | SEG_G, // L
    SEG_C | SEG_D | SEG_E | SEG_G, 0, 0    // O
};

const uint8_t TEXT_PERCENT[] = {
    0, 0,
    SEG_A | SEG_B | SEG_F | SEG_G, // %
    SEG_C | SEG_D | SEG_E | SEG_G  //%
};

const uint8_t TEXT_STOR[] = {
    SEG_A | SEG_C | SEG_D | SEG_F | SEG_G, // S
    SEG_D | SEG_E | SEG_F | SEG_G,         // t
    SEG_C | SEG_D | SEG_E | SEG_G,         // o
    SEG_E | SEG_G                          // r
};

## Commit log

2024-02-04 hardware-ok. firware barelly workin
    [battery-capacity-meter-2024.kicad_pcb, battery-capacity-meter-2024.kicad_sch]
2024-02-05 working v1
    [battery-capacity-meter-2024.kicad_pcb, battery-capacity-meter-2024.kicad_sch, bottom.dxf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]
2024-02-06 add ovp
    [battery-capacity-meter-2024.kicad_pcb, battery-capacity-meter-2024.kicad_sch]
2024-02-07 Ignore battery voltage that is too low
    [main.cpp]
2024-02-11 add overvoltage protection in hardware and cycle modes in firmware
    [battery-capacity-meter-2024.kicad_pcb, battery-capacity-meter-2024.kicad_sch]
2024-02-12 before tracks reset
    [battery-capacity-meter-2024.kicad_pcb, battery-capacity-meter-2024.kicad_sch]
2024-02-12 ready two layers
    [battery-capacity-meter-2024.kicad_pcb, battery-capacity-meter-2024.kicad_sch]
2024-02-12 jlc-pcb order
    [battery-capacity-meter-2024.kicad_pcb, bom.csv, designators.csv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]
2024-02-12 add back 4.150V as stop charge threshold
2024-02-13 set storage voltage to 3.8V; new mode - storage only
2024-07-28 fix missing pcb track
    [battery-capacity-meter-2024.kicad_pcb, battery-capacity-meter-2024.kicad_sch]
2024-07-31 fix state when battery was never connected
    [top.dxf]
